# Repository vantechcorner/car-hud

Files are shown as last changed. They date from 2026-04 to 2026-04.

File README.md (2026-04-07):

# Car HUD

DIY heads-up display: live vehicle data on a **round 240×240** ESP32-S3 display. Data comes from an **ELM327** OBD-II adapter. If the adapter is **Bluetooth Classic** (e.g. BT 3.0), an **ESP32 “bridge”** (NodeMCU-class board) reads the dongle and forwards frames to the HUD over **UART** or **WiFi UDP**.

UI is built with **LVGL** (see also [LVGL Pro](https://pro.lvgl.io/) for the XML/tooling workflow used in `lib/hud_ui/`).

For implementation details, wiring, and PlatformIO env names, see **[HANDOFF.md](HANDOFF.md)**.

## Features

- **OBD-II** mode `01` telemetry: RPM, vehicle speed, coolant temperature, control-module voltage  
- **ESP32-S3** round LCD (default build: Waveshare **ESP32-S3-Touch-LCD-1.28**)  
- **Path A — BLE:** NimBLE to ELM327 **BLE** (when the dongle supports it)  
- **Path B — Bluetooth Classic:** firmware in **`bridge/`** on **ESP32 (NodeMCU)** + **`lolin_s3_mini_1_28_uart_bridge`** or **`lolin_s3_mini_1_28_wifi_bridge`** on the S3  
- **Bench / UI test:** `bridge` env **`esp32_bridge_sim`** (or **`_sim_wifi`**) — no OBD; fake RPM/speed/temp/voltage  

## Hardware (setup in use)

| Component | Description |
|---|---|
| **HUD display** | **Waveshare ESP32-S3-Touch-LCD-1.28** — 1.28″ round **240×240** IPS, capacitive touch, **ESP32-S3**, microSD. PlatformIO: `lolin_s3_mini_1_28` / default **`lolin_s3_mini_1_28_uart_bridge`**. |
| **OBD adapter** | ELM327-class device (e.g. **Bluetooth Classic** / BT3.0 dongle). Configure name/MAC in **`bridge/platformio.ini`** for the bridge build. |
| **Bridge (Classic BT)** | **ESP32 NodeMCU** (or similar ESP32, not S3) running **`bridge/`** — connects to the dongle over BT Classic, sends normalized `41 …` lines to the S3 on **UART** (default pins in `bridge/platformio.ini`: RX **16**, TX **17**) or **WiFi** to the HUD SoftAP. |

**Wiring (UART bridge):** connect **S3 UART** to **bridge UART** (cross TX/RX), common GND, 3V3 logic. Exact S3 pins: **`OBD_BRIDGE_RX_PIN` / `OBD_BRIDGE_TX_PIN`** in root `platformio.ini` (default RX **16**, TX **15** on S3 — verify against your board doc and re-flash if you change pins).

**Note:** ESP32-S3 does **not** speak Bluetooth **Classic**; a separate ESP32 bridge is required for BT3.0 ELM adapters.

## Parameters (dashboard)

- Engine RPM  
- Vehicle speed (km/h)  
- Coolant temperature  
- Battery / control-module voltage  
- OBD link status  

Protocol on the wire: **ISO 15765-4 CAN** between vehicle and adapter; HUD sees **ELM-style ASCII** responses (`41 0C …`, `41 0D …`, etc.).

## UI

Screens are defined under `lib/hud_ui/` (XML + generated C).

| Screen | Content |
|---|---|
| **Boot** | **Mazda** logo — asset `mazda_logo_small` (`lib/hud_ui/images/mazda_logo_small.png` → compiled image), centered on **`boot.xml` / `boot_gen.c`**. |
| **Dashboard** | Round HUD: RPM arc, speed center, voltage / coolant sides, bottom link strip (`dashboard_gen.c`). *Replace the screenshot below with your own in-car photo when you have one.* |
| **Settings** | Device / tuning screens as in repo. |

| Boot (Mazda logo) | Dashboard *(placeholder — swap for real install photo)* | Settings |
|---|---|---|
| Boot Boot — Mazda logo | Dashboard | Settings |

If `lib/hud_ui/screenshots/` is empty locally, add PNGs there or update the paths above after you export captures from hardware.

## Build (quick reference)

```text
# HUD (default env: UART bridge input)
pio run -t upload

# Bridge — OBD + UART to S3
cd bridge && pio run -e esp32_bridge_bt3 -t upload

# Bridge — UI demo without OBD
cd bridge && pio run -e esp32_bridge_sim -t upload
```

See **HANDOFF.md** for WiFi bridge envs, sim WiFi, brownout notes on NodeMCU, and protocol details.

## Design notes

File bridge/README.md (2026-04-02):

# ESP32 Classic Bridge (BT3.0 -> UART)

This firmware is for an ESP32 classic board (ESP32-WROOM/WROVER class) that connects to a Bluetooth Classic ELM327 adapter (e.g. Vgate iCar Pro BT3.0) and forwards parsed OBD lines to the ESP32-S3 HUD over UART.

## Why this bridge exists

`ESP32-S3` supports BLE only, while `Vgate iCar Pro BT3.0` uses Bluetooth Classic.

## Wiring

- Bridge `TX` -> HUD `RX`
- Bridge `RX` -> HUD `TX` (optional, reserved for future use)
- Bridge `GND` -> HUD `GND`

Default pins from `platformio.ini`:

- Bridge UART TX: `GPIO17`
- Bridge UART RX: `GPIO16`

HUD side defaults in `src/main.cpp` when bridge mode is enabled:

- HUD RX: `GPIO16`
- HUD TX: `GPIO15`

You can override these by build flags.

## Build and upload

From this `bridge` folder:

```bash
pio run -e esp32_bridge_bt3
pio run -e esp32_bridge_bt3 -t upload
pio device monitor -b 115200
```

## Adapter config

In `bridge/platformio.ini` you can set both. The firmware **connects by name first**, then tries **MAC** only if the name fails (saves time when name works).

- `-D OBD_BT_NAME=\"V-LINK\"` (tried first)
- `-D OBD_BT_MAC=\"AA:BB:CC:DD:EE:FF\"` (optional fallback)

## Protocol to HUD

The bridge forwards OBD responses as text lines such as:

`41 0C 1A F8`

`41 0D 3C`

The HUD parser reads these lines directly.

## Serial: `ASSERT_WARN(1 8), in lc_task.c`

If you see this line on the ESP32 classic serial monitor while Bluetooth SPP is active, it usually comes from **Espressif Bluedroid** (link-controller task), not from application code. It is often **benign** when traffic is frequent (e.g. polling RPM every 100 ms). If the HUD still receives `41 ...` lines and the car data looks correct, you can ignore it. If you see disconnects or instability, try slightly increasing poll intervals in `bridge/src/main.cpp` (`FAST_INTERVAL`, etc.).

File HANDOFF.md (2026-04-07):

# Car HUD — handoff for Cursor / future sessions

**Last verified (user):** ESP32-S3 round 240×240 UI + ESP32 NodeMCU bridge **sim** profile work end-to-end. Use this file to resume without re-discovering architecture.

---

## Architecture

| Role | Hardware | Firmware | Talks to HUD |
|---|---|---|---|
| **HUD** | ESP32-S3 + 1.28″ 240×240 (e.g. Waveshare S3 Touch LCD 1.28) | Root `platformio.ini` → env `lolin_s3_mini_1_28_uart_bridge` (default) or `*_wifi_bridge` | Receives ELM-style ASCII lines |
| **Bridge** | ESP32 NodeMCU (or similar) | `bridge/` PlatformIO | BT Classic → ELM327, forwards normalized `41 …` lines |

**Data path (production):** OBD dongle ↔ Bridge (BT) ↔ **UART** or **UDP** ↔ S3 `parseObd()` → LVGL subjects (`engine_rpm`, `speed`, `coolant_temp`, `battery_tenths`, `con_error`).

**Data path (bench):** Bridge build **`esp32_bridge_sim`** (UART) or **`esp32_bridge_sim_wifi`** — no Bluetooth/OBD; synthesizes same `41 0D` / `41 0C` / `41 05` / `41 42` lines.

---

## Key source files

| Area | Path | Notes |
|---|---|---|
| HUD OBD parse + BLE / UART / WiFi bridge | `src/main.cpp` | `parseObd()` strips hex, expects `41` mode-01; PIDs 0x0C, 0x0D, 0x05, 0x42 |
| Round dashboard UI | `lib/hud_ui/screens/dashboard_gen.c` | RPM arc, speed block, Volt/Temp sides, OBD strip |
| Subjects init | `lib/hud_ui/hud_ui_gen.c` | `battery_tenths` init `-1` → `-- V`; `coolant_temp` init `-128` → `--°C` until PID 05 |
| Real bridge + sim | `bridge/src/main.cpp` | `#ifdef BRIDGE_SIMULATE` — sim cycle ~40 s ramp/hold/decay RPM & speed |
| Bridge partitions | `bridge/partitions_bridge.csv` | Avoid `huge_app` on 2 MB flash (was causing boot issues) |
| Bridge PlatformIO | `bridge/platformio.ini` | Envs below |

---

## PlatformIO environments (bridge)

- **`esp32_bridge_bt3`** — Production: BT to OBD, UART to S3 (`HUD_UART_RX_PIN` 16, `HUD_UART_TX_PIN` 17 by default in `bridge/platformio.ini`).
- **`esp32_bridge_bt3_wifi`** — BT + WiFi STA → UDP to HUD (`HUD_UDP_PORT` 3333, SSID/pass must match S3 SoftAP if used).
- **`esp32_bridge_sim`** — **No BT/OBD**; UART only; fake vehicle data for UI testing.
- **`esp32_bridge_sim_wifi`** — Same sim over WiFi UDP.

**Brownout on NodeMCU (real bridge):** Mitigations in firmware: `WiFi.mode(WIFI_OFF)` on UART build before BT, delays, `board_build.f_cpu = 160MHz`, `CONFIG_ESP32_BROWNOUT_DET_LVL_SEL_0`. Hardware: solid USB / cap on 3V3 if still brownout.

---

## PlatformIO environments (S3 HUD)

- Default: **`lolin_s3_mini_1_28_uart_bridge`** — `OBD_UART_BRIDGE`, pins `OBD_BRIDGE_RX_PIN` / `OBD_BRIDGE_TX_PIN` (see root `platformio.ini`; must match wiring to NodeMCU UART).
- **`lolin_s3_mini_1_28_wifi_bridge`** — `OBD_WIFI_BRIDGE`, UDP port aligned with bridge WiFi build.

---

## Wire protocol (HUD side)

Bridge must emit **spaced** hex (HUD parser is line-based ASCII), e.g.:

- Speed: `41 0D XX` (km/h)
- RPM: `41 0C AA BB` with RPM = `((A<<8)|B)/4`
- Coolant: `41 05 XX` with °C = `A - 40`
- Voltage: `41 42 AA BB` with mV = `(A<<8)|B`, HUD stores tenths-of-volt

**Bridge `processElmLine`:** Strips spaces, finds `41`, normalizes 6-char (1-byte PID) or 8-char (0x0C, 0x42) from **prefix** of compact hex so padded ELM lines are not dropped.

**Slow PIDs:** Real bridge and direct-BLE HUD path send **both** `0105` and `0142` each slow interval (not strict alternation) so temp/volt are not starved.

---

## UI decisions (dashboard)

- Speed digits: **fixed label width** from `lv_text_get_size("888", …)` + `LV_LABEL_LONG_MODE_CLIP` + `LV_TEXT_ALIGN_CENTER` so multi-digit speed stays visually centered (bind_text alone kept left edge fixed).
- RPM label / `km/h`: slight transform scale (`DASH_RPM_KMH_SMALL`); gap RPM → speed via `align_to(speed_val, rpm_tag, OUT_BOTTOM_MID, DASH_RPM_TO_SPEED_GAP)`.
- OBD status text: slightly smaller (`DASH_LINK_SMALL`).
- Coolant: observer sets `--°C` when value `< -100` (sentinel `-128`).

---

## User-specific config to re-check

- Bridge `OBD_BT_MAC` / `OBD_BT_NAME` in `bridge/platformio.ini`.
- S3 `OBD_BRIDGE_*` pins vs actual wiring (S3 TX → bridge RX, etc.).
- WiFi SSID/password if using WiFi bridge builds.

---

## Build / flash (reference)

```text
# S3 HUD (default env in repo)
pio run -t upload

# Bridge — production UART
cd bridge && pio run -e esp32_bridge_bt3 -t upload

# Bridge — bench sim UART
cd bridge && pio run -e esp32_bridge_sim -t upload
```

---

## Open / future ideas (not blocking)

- Optional core dump partition on bridge to silence `No core dump partition` log (cosmetic).
- If PID `0x42` unsupported on some cars, voltage may stay `-- V`; PID `0x42` formula already matches SAE in `parseObd`.
- Sim: tune `SIM_CYCLE_MS`, `SIM_RPM_IDLE`, `SIM_RPM_MAX` via `-D` in `bridge/platformio.ini` if needed.

---

*End of handoff.*

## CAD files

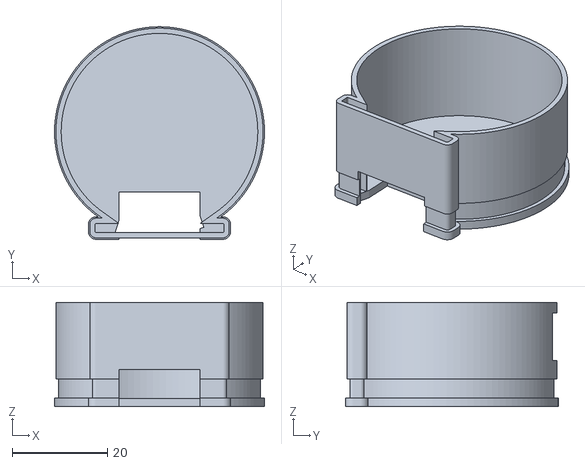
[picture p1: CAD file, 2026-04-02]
mechanical/stl/hud_back_min_tall_v3.stl
44.0 x 44.5 x 21.8

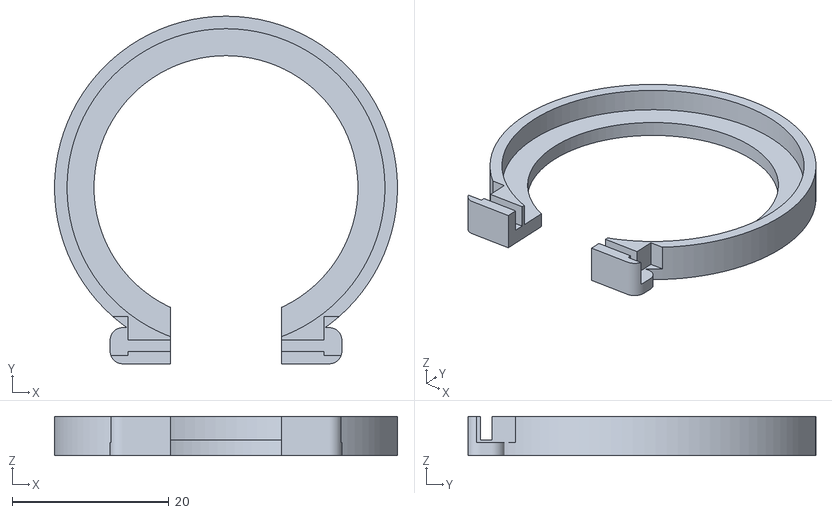
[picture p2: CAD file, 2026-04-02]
mechanical/stl/hud_face_min.stl
43.8 x 44.4 x 5.00

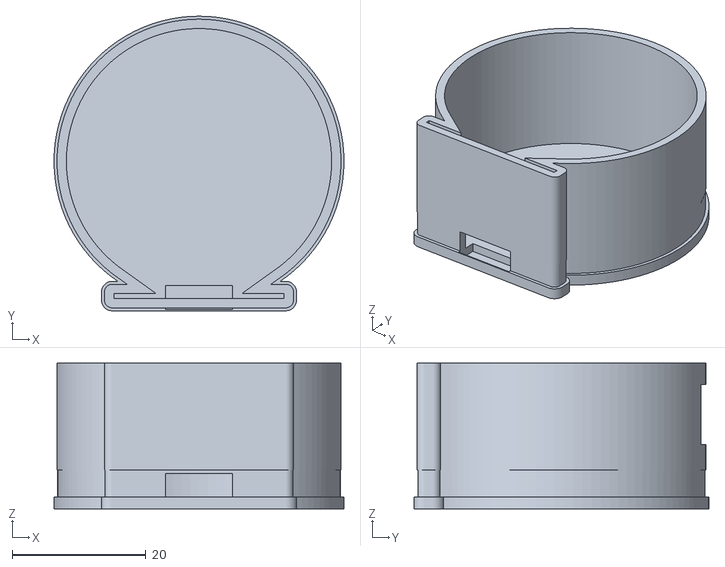
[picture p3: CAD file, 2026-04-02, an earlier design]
mechanical/stl/hud_back_min_tall_v2.stl
43.4 x 44.1 x 21.8

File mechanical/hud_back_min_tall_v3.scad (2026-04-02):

// Tall back cover V3 for hud_face_min
// Fixes:
// - Increase cavity size so ESP32-S3 round board fits
// - Add a much larger USB-C cutout at bottom (so no manual trimming)
// - Keep TOP (+Y) wire slot for header bundle
// Units: mm

$fn = 96;

// Shared geometry (must match hud_face_min.scad)
board_d = 39.49;
board_total_h = 40.36;
board_tail_w = 25.28;
wall = 1.6;

// Front face fit (into hud_face_min)
back_t = 1.8;
rim_h = 4.0;

// Roominess controls
clearance = 0.65;     // outer shell around the board
fit_gap = 0.70;       // loosen rim insert into printed face
tall_h = 16.0;
tall_shrink = 0.30;  // less shrink = more cavity space

// Internal void thickness (reduce to increase cavity)
inner_shell = wall - 0.20;

// Board coords
board_r = board_d / 2;
tail_drop = board_total_h - board_d;

// USB-C cutout parameters (matches hud_face_min values + extra margin)
usb_w = 13.0;         // width in X direction
usb_h = 5.5;          // height in Z direction (for the slot)
usb_cut_y = -(board_r + tail_drop) + 2.0;
usb_cut_x = usb_w + 4.0;
usb_cut_y_len = 12.0; // open more towards Y
usb_cut_z_len = 10.0; // open deeper into thickness

// Top wire slot (+Y)
wire_slot_w = 24.0;
wire_slot_h = 10.0;
wire_slot_y = 14.0;
// Approx outer radius at top of round part (for placing slot)
r_outer_top = board_r + clearance + wall;

module board_profile_2d(extra = 0) {
    union() {
        circle(d = board_d + extra * 2);
        translate([0, -(board_r + tail_drop / 2)])
            square([board_tail_w + extra * 2, tail_drop + extra], center = true);
    }
}

module outer_profile_2d() {
    offset(r = wall)
        board_profile_2d(extra = clearance);
}

module tall_shell_v3() {
    difference() {
        union() {
            // Main cover plate
            linear_extrude(height = back_t)
                outer_profile_2d();

            // Insert rim into hud_face_min
            translate([0, 0, back_t])
                linear_extrude(height = rim_h)
                    offset(delta = -(fit_gap + 0.15))
                        outer_profile_2d();

            // Rear extension (battery cavity cap)
            translate([0, 0, back_t + rim_h])
                linear_extrude(height = tall_h)
                    offset(delta = -tall_shrink)
                        outer_profile_2d();
        }

        // Hollow inner volume (bigger cavity)
        translate([0, 0, back_t - 0.1])
            linear_extrude(height = rim_h + tall_h + 0.3)
                offset(delta = -inner_shell)
                    outer_profile_2d();

        // --- Large USB-C cutout at bottom ---
        // Carve a rectangular trench through the shell depth around the USB connector.
        translate([0, usb_cut_y, back_t + rim_h * 0.25])
            cube([usb_cut_x, usb_cut_y_len, usb_cut_z_len], center = true);

        // Small chamfer relief near USB corners (helps the angled connector)
        for (sx = [-1, 1]) {
            translate([sx * (usb_cut_x / 2 - 3.0), usb_cut_y + sx * 0.5, back_t + rim_h * 0.25])
                rotate([0, 0, sx * 18])
                    cube([6.0, 6.0, usb_cut_z_len], center = true);
        }

        // --- TOP (+Y) wire slot for header bundle ---
        translate([0, r_outer_top + wire_slot_y / 2 - 1.2, back_t + rim_h + tall_h * 0.55])
            cube([wire_slot_w, wire_slot_y, wire_slot_h], center = true);

        // Rear small pass + vent (optional)
        translate([0, -6, back_t + rim_h + tall_h - 0.1])
            cylinder(h = 2.0, d = 6.5);

        // Vents (simple)
        for (i = [-2:2]) {
            translate([i * 5.2, 8.5, back_t + rim_h + tall_h - 0.1])
                cube([3.0, 8.0, 2.0], center = true);
        }
    }
}

tall_shell_v3();

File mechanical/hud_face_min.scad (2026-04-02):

// Minimal front face for Waveshare ESP32-S3 Touch LCD 1.28
// Goal: smallest possible outer size that still seats the board.
// Units: mm
//
// Export examples:
//   openscad -o hud_face_min.stl hud_face_min.scad

$fn = 96;

// ----- Board dimensions (from provided drawing) -----
board_d = 39.49;        // main circular board diameter
board_total_h = 40.36;  // overall height including lower tail
board_tail_w = 25.28;   // lower width
usb_w = 13.0;           // USB-C slot width (connector + shell tolerance)
usb_h = 5.5;            // USB-C slot height

// ----- Fit / print parameters -----
clearance = 0.55;       // board pocket — extra room near USB tail / corners
wall = 1.6;             // thin wall for compact form
front_t = 2.0;          // front plate thickness
seat_depth = 3.0;       // back pocket depth
bezel = 1.1;            // visible ring around LCD opening

// Active area from drawing: 33.40
lcd_open_d = 33.40 + 0.3; // tiny margin to avoid clipping

// Derived
board_r = board_d / 2;
tail_drop = board_total_h - board_d; // extra height below circle

module board_profile_2d(extra = 0) {
    // Approximate Waveshare "round + short tail" board shape.
    // Keep shape simple and robust for OpenSCAD.
    union() {
        circle(d = board_d + extra * 2);
        translate([0, -(board_r + tail_drop / 2)])
            square([board_tail_w + extra * 2, tail_drop + extra], center = true);
    }
}

module outer_profile_2d() {
    offset(r = wall)
        board_profile_2d(extra = clearance);
}

module face_shell() {
    // Bottom of tail (USB end): center of cut sits slightly outward so plastic lip clears connector
    usb_y = -(board_r + tail_drop) + 1.4;
    usb_cut_depth_y = 9.0;

    difference() {
        // Main front face
        linear_extrude(height = front_t + seat_depth)
            outer_profile_2d();

        // Back pocket where board sits
        translate([0, 0, front_t])
            linear_extrude(height = seat_depth + 0.2)
                board_profile_2d(extra = clearance);

        // Front LCD window
        translate([0, 0, -0.1])
            cylinder(h = front_t + 0.3, d = lcd_open_d);

        // USB-C: cut through full shell depth so board can seat flat (no lip riding on port)
        translate([0, usb_y, (front_t + seat_depth) / 2 - 0.15])
            cube([usb_w + 1.2, usb_cut_depth_y, front_t + seat_depth + 0.6], center = true);

        // Inner corner relief where round body meets tail (both sides of USB)
        for (sx = [-1, 1]) {
            translate([sx * (board_tail_w / 2 + clearance + 0.9), -board_r + 0.8, front_t + seat_depth / 2 - 0.1])
                cube([3.2, 5.0, seat_depth + 0.5], center = true);
        }
    }
}

face_shell();

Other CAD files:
mechanical/hud_back_min_tall_v2.scad

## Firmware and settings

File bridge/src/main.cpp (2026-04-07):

#include <Arduino.h>
#include <stdio.h>
#if !defined(BRIDGE_SIMULATE)
#include <BluetoothSerial.h>
#endif
#if defined(HUD_USE_WIFI) || defined(BRIDGE_SIMULATE)
#include <WiFi.h>
#endif
#if defined(HUD_USE_WIFI)
#include <WiFiUdp.h>
#endif
#if !defined(HUD_USE_WIFI) && !defined(BRIDGE_SIMULATE)
/* UART-only OBD bridge: Wi-Fi off so BT Classic peak is not stacked (brownout). */
#include <WiFi.h>
#endif

// ---------- Bridge output to ESP32-S3 HUD ----------
#if defined(HUD_USE_WIFI)
#ifndef HUD_UDP_PORT
#define HUD_UDP_PORT 3333
#endif
// Default: send UDP to WiFi.gatewayIP() (HUD as SoftAP => 192.168.4.1).
WiFiUDP hudUdp;
#else
#ifndef HUD_UART_BAUD
#define HUD_UART_BAUD 115200
#endif
#ifndef HUD_UART_RX_PIN
#define HUD_UART_RX_PIN 16
#endif
#ifndef HUD_UART_TX_PIN
#define HUD_UART_TX_PIN 17
#endif
#endif

// ---------- OBD adapter connection ----------
// build_flags: OBD_BT_NAME (tried first), OBD_BT_MAC (fallback if name fails)
// -D OBD_BT_NAME=\"V-LINK\"
// -D OBD_BT_MAC=\"AA:BB:CC:DD:EE:FF\"
#ifndef OBD_BT_MAC
#define OBD_BT_MAC ""
#endif
#ifndef OBD_BT_NAME
#define OBD_BT_NAME "V-LINK"
#endif

#if !defined(BRIDGE_SIMULATE)
BluetoothSerial SerialBT;
#endif
#if !defined(HUD_USE_WIFI)
HardwareSerial HudSerial(2);
#endif

#if !defined(BRIDGE_SIMULATE)
static String lineBuffer;
static bool obdReady = false;
#endif
static uint32_t lastAltPoll = 0;
static uint32_t lastSlow = 0;
#if !defined(BRIDGE_SIMULATE)
static uint32_t lastReconnectTry = 0;
#endif
static bool pollSpeedNext = true; // xen kẽ 010D / 010C cho cảm giác “real-time”
#if defined(HUD_USE_WIFI)
static uint32_t lastWifiTry = 0;
#endif

// ELM327 half-duplex: one request at a time. Alternating speed/RPM avoids starving either PID.
#ifndef BRIDGE_ALTERNATE_POLL_MS
#define BRIDGE_ALTERNATE_POLL_MS 80U
#endif
#ifndef BRIDGE_TEMP_MS
#define BRIDGE_TEMP_MS 4000U
#endif

static const uint32_t ALT_POLL_INTERVAL = BRIDGE_ALTERNATE_POLL_MS;
static const uint32_t SLOW_INTERVAL = BRIDGE_TEMP_MS;

#if !defined(BRIDGE_SIMULATE)
void sendElm(const char *cmd)
{
  SerialBT.print(cmd);
  SerialBT.print("\r");
}
#endif

#if defined(HUD_UDP_USE_STATIC_TARGET)
static IPAddress hudUdpTarget(
    HUD_UDP_TARGET_OCT1, HUD_UDP_TARGET_OCT2, HUD_UDP_TARGET_OCT3, HUD_UDP_TARGET_OCT4);
#endif

void emitToHud(const String &s)
{
#if defined(HUD_USE_WIFI)
  if (WiFi.status() != WL_CONNECTED)
    return;
#if defined(HUD_UDP_USE_STATIC_TARGET)
  IPAddress target = hudUdpTarget;
#else
  IPAddress target = WiFi.gatewayIP();
  if ((uint32_t)target == 0)
    return;
#endif
  hudUdp.beginPacket(target, HUD_UDP_PORT);
  hudUdp.print(s);
  hudUdp.endPacket();
#else
  HudSerial.println(s);
#endif
}

#if !defined(BRIDGE_SIMULATE)
void processElmLine(String line)
{
  line.trim();
  line.toUpperCase();

  if (line.isEmpty())
    return;

  // Ignore command echo and status noise.
  if (line == "OK" || line.startsWith("AT") || line.startsWith("SEARCHING"))
    return;

  // Forward OBD mode 01 response.
  // Some ELM adapters respond as compact hex without spaces, e.g.:
  //   "41 0C 1A F8"  OR  "410C1AF8"
  // The S3 HUD parser currently expects spaced form.
  String s = line;
  s.replace(" ", "");

  // Some adapters include headers, e.g. "7E8..." or other prefixes before the "41" payload.
  // Try to locate the start of the mode-01 response anywhere in the line.
  int p = s.indexOf("41");
  if (p > 0)
    s = s.substring(p);

  if (s.length() >= 6 && s.startsWith("41"))
  {
    /* Many ELM lines are longer than 6/8 hex (padding, multi-frame tail). Only exact
     * length matched before — real cars often sent e.g. "41057B...." and we dropped it. */
    String pid = s.substring(2, 4);
    unsigned long ppl = strtoul(pid.c_str(), nullptr, 16);
    String normalized;
    if (ppl == 0x0C || ppl == 0x42)
    {
      if (s.length() < 8)
        return;
      String v1 = s.substring(4, 6);
      String v2 = s.substring(6, 8);
      normalized = "41 " + pid + " " + v1 + " " + v2;
    }
    else
    {
      String v1 = s.substring(4, 6);
      normalized = "41 " + pid + " " + v1;
    }
    emitToHud(normalized);
#ifdef BRIDGE_DEBUG
    Serial.printf("[bridge] ok line=%s -> hud=%s\n", line.c_str(), normalized.c_str());
#endif
  }
}

void processElmIncoming()
{
  while (SerialBT.available())
  {
    char c = (char)SerialBT.read();
    if (c == '\r' || c == '\n' || c == '>')
    {
      if (!lineBuffer.isEmpty())
      {
        processElmLine(lineBuffer);
        lineBuffer = "";
      }
      continue;
    }

    if ((uint8_t)c < 32 || (uint8_t)c > 126)
      continue;

    lineBuffer += c;
    if (lineBuffer.length() > 128)
    {
      lineBuffer = "";
    }
  }
}

bool connectObdAdapter()
{
  // Name first (usually faster when it works); MAC only if name fails.
  if (SerialBT.connect(OBD_BT_NAME))
    return true;
  if (strlen(OBD_BT_MAC) > 0)
    return SerialBT.connect(OBD_BT_MAC);
  return false;
}

void initElm()
{
  sendElm("ATZ");
  delay(800);
  sendElm("ATE0");
  delay(250);
  sendElm("ATL0");
  delay(250);
  sendElm("ATS0");
  delay(250);
  sendElm("ATSP6");
  delay(300);
  obdReady = true;
  lastAltPoll = lastSlow = millis();
  pollSpeedNext = true;
}

#endif /* !BRIDGE_SIMULATE */

#if defined(BRIDGE_SIMULATE)

#ifndef SIM_CYCLE_MS
#define SIM_CYCLE_MS 40000U
#endif
#ifndef SIM_RPM_IDLE
#define SIM_RPM_IDLE 720U
#endif
#ifndef SIM_RPM_MAX
#define SIM_RPM_MAX 5200U
#endif

static float sim_smoothstep(float t)
{
  if (t <= 0.f)
    return 0.f;
  if (t >= 1.f)
    return 1.f;
  return t * t * (3.f - 2.f * t);
}

static uint16_t sim_rpm_at(uint32_t ms)
{
  const uint32_t c = SIM_CYCLE_MS;
  const uint32_t T_UP = c * 30 / 100;
  const uint32_t T_HOLD = c * 45 / 100;
  const uint32_t T_DOWN = c * 78 / 100;
  uint32_t t = ms % c;
  const uint16_t lo = SIM_RPM_IDLE;
  const uint16_t hi = SIM_RPM_MAX;

  if (t < T_UP)
  {
    float u = sim_smoothstep((float)t / (float)T_UP);
    return lo + (uint16_t)(u * (float)(hi - lo));
  }
  if (t < T_HOLD)
    return hi;
  if (t < T_DOWN)
  {
    float u = sim_smoothstep((float)(t - T_HOLD) / (float)(T_DOWN - T_HOLD));
    return hi - (uint16_t)(u * (float)(hi - lo));
  }
  return lo;
}

static uint8_t sim_kmh_at(uint32_t ms)
{
  uint16_t rpm = sim_rpm_at(ms);
  if (rpm <= 850)
    return 0;
  uint32_t v = (uint32_t)(rpm - 800) * 125U / (unsigned)(SIM_RPM_MAX - 800);
  if (v > 220)
    v = 220;
  return (uint8_t)v;
}

static int16_t sim_coolant_at(uint32_t ms)
{
  uint16_t rpm = sim_rpm_at(ms);
  int span = (int)SIM_RPM_MAX - (int)SIM_RPM_IDLE;
  int base = 72 + (int)((rpm - SIM_RPM_IDLE) * 22 / (span > 1 ? span : 1));
  if (base < 72)
    base = 72;
  if (base > 96)
    base = 96;
  return (int16_t)base;
}

static void sim_emit_0d(uint8_t kmh)
{
  char b[20];
  snprintf(b, sizeof(b), "41 0D %02X", (unsigned)kmh);
  emitToHud(String(b));
}

static void sim_emit_0c(uint16_t rpm)
{
  uint32_t raw = (uint32_t)rpm * 4U;
  if (raw > 0xFFFFu)
    raw = 0xFFFFu;
  unsigned hi = (raw >> 8) & 0xFF;
  unsigned lo = raw & 0xFF;
  char b[24];
  snprintf(b, sizeof(b), "41 0C %02X %02X", hi, lo);
  emitToHud(String(b));
}

static void sim_emit_05_c(int16_t temp_c)
{
  int a = (int)temp_c + 40;
  if (a < 0)
    a = 0;
  if (a > 255)
    a = 255;
  char b[20];
  snprintf(b, sizeof(b), "41 05 %02X", (unsigned)a);
  emitToHud(String(b));
}

static void sim_emit_42_mv(uint16_t mv)
{
  unsigned hi = (mv >> 8) & 0xFF;
  unsigned lo = mv & 0xFF;
  char b[24];
  snprintf(b, sizeof(b), "41 42 %02X %02X", hi, lo);
  emitToHud(String(b));
}

void setup()
{
  Serial.begin(115200);
  delay(200);
#if defined(HUD_USE_WIFI)
  WiFi.mode(WIFI_STA);
  WiFi.setSleep(false);
  Serial.println("Car HUD bridge SIMULATOR (WiFi -> HUD UDP)");
  Serial.printf("Join AP SSID=%s port=%u\n", WIFI_STA_SSID, (unsigned)HUD_UDP_PORT);
  WiFi.begin(WIFI_STA_SSID, WIFI_STA_PASS);
#else
  WiFi.mode(WIFI_OFF);
  HudSerial.begin(HUD_UART_BAUD, SERIAL_8N1, HUD_UART_RX_PIN, HUD_UART_TX_PIN);
  Serial.println("Car HUD bridge SIMULATOR (UART -> HUD, no BT/OBD)");
  Serial.printf("HUD UART TX=%d RX=%d baud=%u\n", HUD_UART_TX_PIN, HUD_UART_RX_PIN,
                (unsigned)HUD_UART_BAUD);
#endif
  lastAltPoll = lastSlow = millis();
  pollSpeedNext = true;
}

void loop()
{
#if defined(HUD_USE_WIFI)
  if (WiFi.status() != WL_CONNECTED)
  {
    uint32_t nw = millis();
    if (nw - lastWifiTry > 3000)
    {
      lastWifiTry = nw;
      Serial.println("WiFi (sim) reconnecting...");
      WiFi.disconnect(true, false);
      WiFi.begin(WIFI_STA_SSID, WIFI_STA_PASS);
    }
  }
#endif

  uint32_t now = millis();

  if (now - lastAltPoll >= ALT_POLL_INTERVAL)
  {
    lastAltPoll = now;
    uint16_t r = sim_rpm_at(now);
    uint8_t k = sim_kmh_at(now);
    if (pollSpeedNext)
      sim_emit_0d(k);
    else
      sim_emit_0c(r);
    pollSpeedNext = !pollSpeedNext;
  }

  if (now - lastSlow >= SLOW_INTERVAL)
  {
    lastSlow = now;
    sim_emit_05_c(sim_coolant_at(now));
    uint16_t mv = (uint16_t)(13700u + (unsigned)sim_rpm_at(now) / 200U);
    if (mv > 14500)
      mv = 14500;
    sim_emit_42_mv(mv);
  }

  delay(5);
}

#else

void setup()
{
  Serial.begin(115200);
  delay(400); /* USB enumerate + bulk cap charge before radio */

#if !defined(HUD_USE_WIFI)
  WiFi.mode(WIFI_OFF);
#endif

  // BT Classic before WiFi on dual-radio builds reduces coexistence panics.
  if (!SerialBT.begin("CarHUD-Bridge", true))
  {
    Serial.println("Bluetooth init failed");
  }

#if defined(HUD_USE_WIFI)
  delay(350); /* avoid BT + Wi-Fi scan peak overlapping on weak 5 V */
  WiFi.mode(WIFI_STA);
  // Modem sleep can add 100–300ms+ jitter on STA → HUD; HUD path needs low latency.
  WiFi.setSleep(false);
  Serial.println("Car HUD BT3.0 bridge (WiFi -> S3 HUD)");
  Serial.printf("Joining AP SSID=%s for UDP port %u\n", WIFI_STA_SSID, (unsigned)HUD_UDP_PORT);
  WiFi.begin(WIFI_STA_SSID, WIFI_STA_PASS);
#else
  HudSerial.begin(HUD_UART_BAUD, SERIAL_8N1, HUD_UART_RX_PIN, HUD_UART_TX_PIN);
  Serial.println("Car HUD BT3.0 bridge starting...");
  Serial.printf("HUD UART TX=%d RX=%d baud=%d\n", HUD_UART_TX_PIN, HUD_UART_RX_PIN, HUD_UART_BAUD);
#endif
}

void loop()
{
#if defined(HUD_USE_WIFI)
  if (WiFi.status() != WL_CONNECTED)
  {
    uint32_t nw = millis();
    if (nw - lastWifiTry > 3000)
    {
      lastWifiTry = nw;
      Serial.println("WiFi reconnecting...");
      WiFi.disconnect(true, false);
      WiFi.begin(WIFI_STA_SSID, WIFI_STA_PASS);
    }
  }
#endif

  if (!SerialBT.connected())
  {
    obdReady = false;
    uint32_t now = millis();
    if (now - lastReconnectTry > 2500)
    {
      lastReconnectTry = now;
      if (connectObdAdapter())
      {
        Serial.println("OBD connected");
        initElm();
      }
      else
      {
        Serial.println("OBD connect retry...");
      }
    }
    delay(20);
    return;
  }

  processElmIncoming();

  if (!obdReady)
  {
    initElm();
    return;
  }

  uint32_t now = millis();

  if (now - lastAltPoll >= ALT_POLL_INTERVAL)
  {
    lastAltPoll = now;
    if (pollSpeedNext)
      sendElm("010D"); // speed
    else
      sendElm("010C"); // RPM
    pollSpeedNext = !pollSpeedNext;
  }

  if (now - lastSlow >= SLOW_INTERVAL)
  {
    lastSlow = now;
    sendElm("0105"); // coolant temp
    delay(40);
    sendElm("0142"); // control module voltage (many ECUs; skip if unsupported)
  }

  delay(5);
}

#endif /* BRIDGE_SIMULATE */

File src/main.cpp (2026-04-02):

/*
   MIT License

  Copyright (c) 2025 Felix Biego

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
  ______________  _____
  ___  __/___  /_ ___(_)_____ _______ _______
  __  /_  __  __ \__  / _  _ \__  __ `/_  __ \
  _  __/  _  /_/ /_  /  /  __/_  /_/ / / /_/ /
  /_/     /_.___/ /_/   \___/ _\__, /  \____/
                              /____/

*/

#include <Arduino.h>
#include <cstring>
#include "main.h"
#include <Preferences.h>
#include "hud_ui.h"
#if !defined(OBD_UART_BRIDGE) && !defined(OBD_WIFI_BRIDGE)
#include <NimBLEDevice.h>
#endif
#include <Timber.h>

#if defined(OBD_UART_BRIDGE) || defined(OBD_WIFI_BRIDGE)
#define OBD_REMOTE_BRIDGE 1
#endif

#define LVGL_LOCK() xSemaphoreTakeRecursive(lvgl_mutex, portMAX_DELAY)
#define LVGL_UNLOCK() xSemaphoreGiveRecursive(lvgl_mutex)

#ifdef OBD_WIFI_BRIDGE
#include <WiFi.h>
#include <WiFiUdp.h>
#ifndef OBD_WIFI_UDP_PORT
#define OBD_WIFI_UDP_PORT 3333
#endif
WiFiUDP obdWifiUdp;
#endif

#ifdef OBD_UART_BRIDGE
#ifndef OBD_BRIDGE_BAUD
#define OBD_BRIDGE_BAUD 115200
#endif
#ifndef OBD_BRIDGE_RX_PIN
#define OBD_BRIDGE_RX_PIN 16
#endif
#ifndef OBD_BRIDGE_TX_PIN
#define OBD_BRIDGE_TX_PIN 15
#endif

HardwareSerial OBDBridgeSerial(1);
#endif

#if defined(OBD_REMOTE_BRIDGE)
static uint32_t lastBridgePacket = 0;
#endif

// Locking LVGL calls to prevent concurrent access
// This is important because LVGL is not thread-safe
// and we need to ensure that only one task is accessing it at a time
// This is done using a recursive mutex
#define LVGL_EXEC(code) \
  do                    \
  {                     \
    if (LVGL_LOCK())    \
    {                   \
      code;             \
      LVGL_UNLOCK();    \
    }                   \
  } while (0)

/* ---------- OBD COMMANDS (ASCII + CR) ---------- */
const uint8_t CMD_ATZ[] = {0x41, 0x54, 0x5A, 0x0D};               // Reset (ATZ)
const uint8_t CMD_ATE0[] = {0x41, 0x54, 0x45, 0x30, 0x0D};        // Echo off (ATE0)
const uint8_t CMD_ATSP6[] = {0x41, 0x54, 0x53, 0x50, 0x36, 0x0D}; // Set protocol to CAN 11/500 (ATSP6)

const uint8_t CMD_SPEED[] = {0x30, 0x31, 0x30, 0x44, 0x0D}; // Vehicle speed (010D)
const uint8_t CMD_RPM[] = {0x30, 0x31, 0x30, 0x43, 0x0D};   // Engine RPM (010C)
const uint8_t CMD_TEMP[] = {0x30, 0x31, 0x30, 0x35, 0x0D};  // Coolant Temperature (0105)
const uint8_t CMD_VOLT[] = {0x30, 0x31, 0x34, 0x32, 0x0D};  // Control module voltage (0142)

Preferences prefs;
/* USBSerial is provided by Arduino-ESP32 core for ESP32-S3 (HWCDC); do not define it here. */

/* ---------- LVGL DISPLAY ---------- */
uint8_t lv_buffer[2][LV_BUFFER_SIZE];
lv_obj_t *boot_screen;
lv_obj_t *dashboard_screen;
lv_obj_t *settings_screen;
SemaphoreHandle_t lvgl_mutex;

bool should_restart = false;

static uint32_t lastFast = 0;   // rpm
static uint32_t lastMedium = 0; // speed
static uint32_t lastSlow = 0;   // coolant temp

const uint32_t FAST_INTERVAL = 100;    // 0.1 seconds
const uint32_t MEDIUM_INTERVAL = 1000; // 1 second
const uint32_t SLOW_INTERVAL = 10000;  // 10 seconds

#ifndef OBD_REMOTE_BRIDGE
/* OBD UUIDs (16-bit, vendor specific) */
static NimBLEUUID OBD_SERVICE_UUID("FFF0");
static NimBLEUUID OBD_CHAR_UUID("FFF1");

static const NimBLEAdvertisedDevice *obdDevice = nullptr;
static NimBLEClient *client = nullptr;
static NimBLERemoteCharacteristic *obdChar = nullptr;
static NimBLEScan *scan = nullptr;
#endif

/* ---------- HEX UTILS ---------- */
static uint8_t hexToByte(uint8_t hi, uint8_t lo)
{
  hi = (hi <= '9') ? (uint8_t)(hi - '0') : (uint8_t)((hi & ~0x20) - 'A' + 10);
  lo = (lo <= '9') ? (uint8_t)(lo - '0') : (uint8_t)((lo & ~0x20) - 'A' + 10);
  return (hi << 4) | lo;
}

static bool isHexDigit(uint8_t c)
{
  return (c >= '0' && c <= '9') || (c >= 'A' && c <= 'F') || (c >= 'a' && c <= 'f');
}

/**
 * Format byte buffer to hex String
 *
 * @param data    Input byte buffer
 * @param len     Number of bytes
 * @param prefix  Add "0x" before each byte
 * @param space   Add space between bytes
 * @param wrap    Bytes per line (0 = no wrap)
 */
String formatHexString(
    const uint8_t *data,
    size_t len,
    bool prefix = true,
    bool space = true,
    uint8_t wrap = 0)
{
  const char *hex = "0123456789ABCDEF";
  String out;
  out.reserve(len * (prefix ? 4 : 2) + len); // avoid reallocations

  for (size_t i = 0; i < len; i++)
  {
    if (wrap && i > 0 && (i % wrap) == 0)
      out += '\n';

    if (prefix)
      out += "0x";

    out += hex[(data[i] >> 4) & 0x0F];
    out += hex[data[i] & 0x0F];

    if (space && i < len - 1)
      out += ' ';
  }

  return out;
}

/* ---------- SIMPLE PARSER ---------- */
/* Accepts ELM-style ASCII: "41 0D 3A", "410D3A", or mixed; extracts hex digits only.
 * Mode 01 single-byte PIDs need 6 hex chars (41 + PID + 1 data byte); RPM needs 8. */
void parseObd(const uint8_t *data, size_t len)
{
  if (len < 4)
    return;

  char scratch[96];
  size_t slen = len < sizeof(scratch) - 1 ? len : sizeof(scratch) - 1;
  memcpy(scratch, data, slen);
  scratch[slen] = '\0';
  if (strstr(scratch, "ERROR") != nullptr)
  {
    LVGL_EXEC(lv_subject_set_int(&can_error, 1));
    return;
  }

  char hex[32];
  size_t nh = 0;
  for (size_t i = 0; i < len && nh < sizeof(hex) - 1; i++)
  {
    if (isHexDigit(data[i]))
      hex[nh++] = (char)data[i];
  }
  hex[nh] = '\0';

  if (nh < 6)
    return;
  if (hex[0] != '4' || hex[1] != '1')
    return;

  uint8_t pid = hexToByte((uint8_t)hex[2], (uint8_t)hex[3]);

  switch (pid)
  {
  case 0x0D: // Speed
  {
    if (nh < 6)
      return;
    uint8_t A = hexToByte((uint8_t)hex[4], (uint8_t)hex[5]);
    Timber.i("Speed: %u km/h\n", A);
    LVGL_EXEC(lv_subject_set_int(&speed, (int)A));
    break;
  }

  case 0x0C: // RPM
  {
    if (nh < 8)
      return;
    uint8_t A = hexToByte((uint8_t)hex[4], (uint8_t)hex[5]);
    uint8_t B = hexToByte((uint8_t)hex[6], (uint8_t)hex[7]);
    float rpm = ((A << 8) | B) / 4.0f;
    Timber.i("RPM: %.0f\n", rpm);
    LVGL_EXEC(lv_subject_set_int(&engine_rpm, (int)rpm));
    break;
  }

  case 0x05: // Coolant temp
  {
    if (nh < 6)
      return;
    uint8_t A = hexToByte((uint8_t)hex[4], (uint8_t)hex[5]);
    float temp = A - 40.0f;
    Timber.i("Coolant: %.1f C\n", temp);
    LVGL_EXEC(lv_subject_set_int(&coolant_temp, (int)temp));
    break;
  }

  case 0x42: // Control module voltage (mV in response)
  {
    if (nh < 8)
      return;
    uint8_t A = hexToByte((uint8_t)hex[4], (uint8_t)hex[5]);
    uint8_t B = hexToByte((uint8_t)hex[6], (uint8_t)hex[7]);
    int mv = (A << 8) | B;
    int tenths = (mv + 50) / 100;
    Timber.i("Battery: %d.%d V\n", tenths / 10, tenths % 10);
    LVGL_EXEC(lv_subject_set_int(&battery_tenths, tenths));
    break;
  }

  default:
    return;
  }
  LVGL_EXEC(lv_subject_set_int(&can_error, 0));
}

void deep_sleep_restart()
{
  /* Here we use deep sleep so we can detect the wakeup source to skip boot logo during startup */
  esp_sleep_enable_timer_wakeup(1000);
  esp_deep_sleep_start();
}
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

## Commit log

2026-04-02 Custom HUD UI for Mazda
    [hud_back_min_tall_v2.scad, hud_back_min_tall_v2.stl, hud_back_min_tall_v3.scad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]
2026-04-02 Fixes for Temp & Battery. UI adjustment
    [main.cpp]
2026-04-07 Fix UI for speed & Update readme
    [main.cpp]
